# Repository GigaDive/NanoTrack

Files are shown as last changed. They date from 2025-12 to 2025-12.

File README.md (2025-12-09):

# NanoTrack v0.1: A Modular HCI Platform

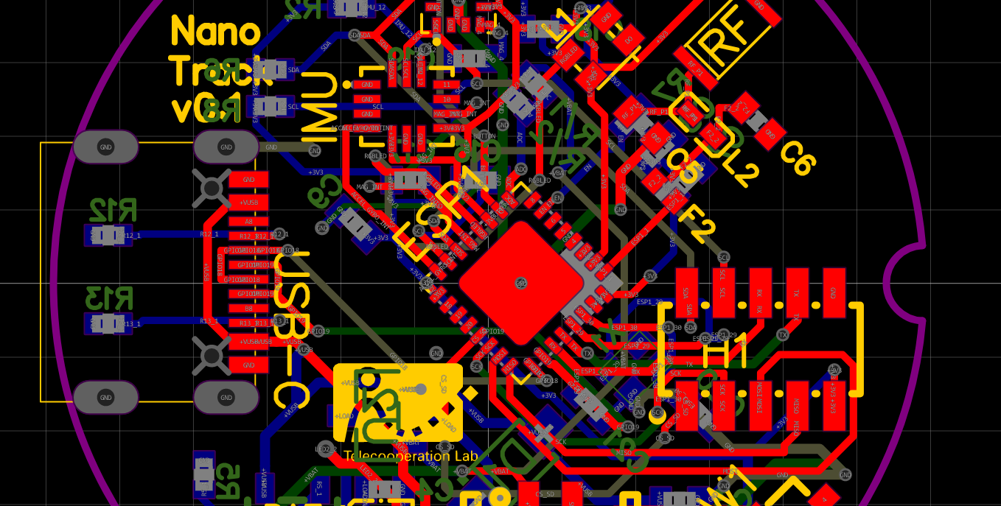
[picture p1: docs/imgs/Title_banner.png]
NanoTrack Board Wiring


The NanoTrack v0.1 is a versatile, small form-factor hardware platform for human-computer interaction (HCI) projects. Based on the ESP32-C3, it's designed for sensor data collection, actuator control, and direct device-to-device communication using ESP-NOW. Its modular design allows for easy expansion and customization.

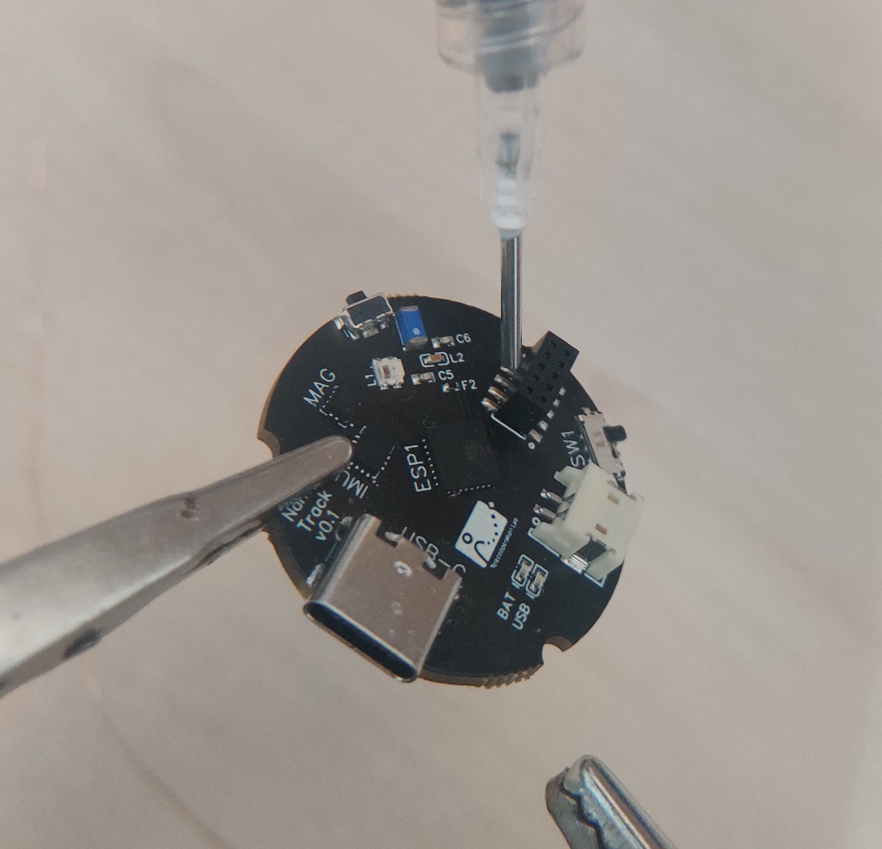
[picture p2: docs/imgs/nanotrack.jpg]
NanoTrack Board PCB


## Hardware

### Specifications

- **Processor**: ESP32-C3 (single-core RISC-V @ 160MHz)
- **Sensors**: Integrated 6-axis IMU (MPU-6050) with accelerometer and gyroscope.
- **Connectivity**: Wi-Fi, ESP-NOW, USB-C (for charging and programming).
- **Features**:
    - RGB-LED for status indication.
    - Physical LiPo battery disconnect switch.
    - User-programmable button.
    - Onboard battery charging and protection circuit.

### Pinout

| Function | PIN | Mode |
| --- | --- | --- |
| MISO | 24 | SPI |
| MOSI | 23 | SPI |
| SCK | 22 | SPI |
| CS_SD | 21 | SPI |
| SDA | 14 | I2C |
| SCL | 15 | I2C |
| Button | 10 | Input |
| RGB LED  | 12 | Output |
| Battery Voltage | 9 | Input |
| Accel /Gyro Programmable Interrupt 1  | 16 | Input |
| Accel /Gyro Programmable Interrupt 2 | 13 | Input |

### Modularity: Board-to-Board Connector

The NanoTrack is intended to use pogo pins for its modular board-to-board connections, allowing for a pressure-fit connection between the main board and extension modules. This design supports SPI, I2C, and serial communication for plug-and-play functionality. In its current state it uses dupon pin header as connection interface. A version with flatcables was also planned, but discarded.

### Casing

The project includes a 3D-printable case designed in Fusion 360. The current iteration is a round, pressure-fit case, with future designs moving towards using M2.5 brass standoffs for more robust mounting.

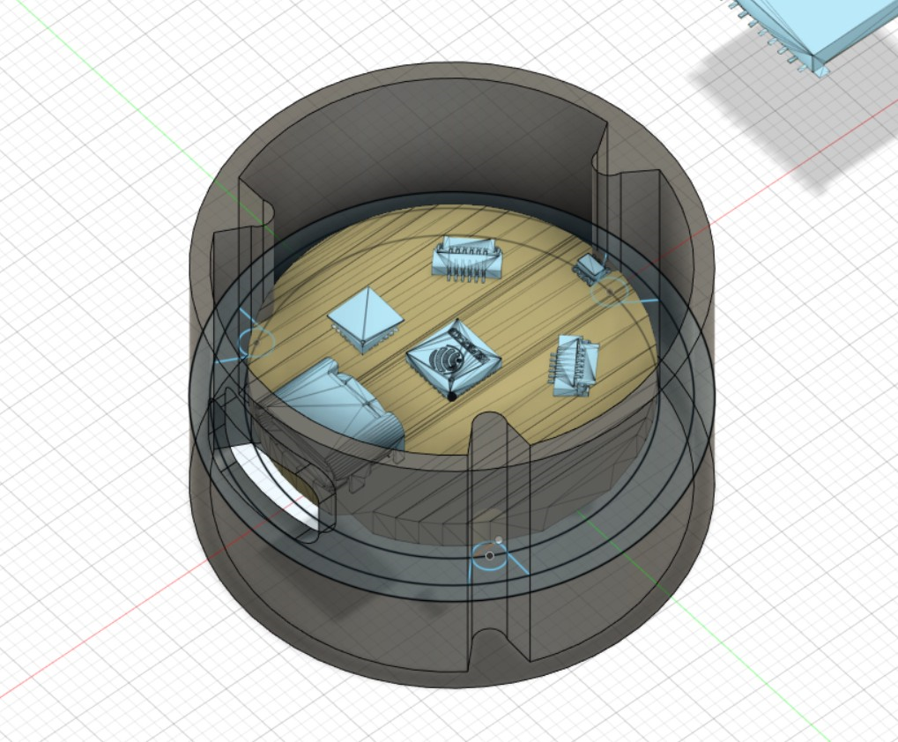
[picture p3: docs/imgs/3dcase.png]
3D Printed Case


### Schematics

- [Main Board Schematic (v0.4)](docs/v04/schematic_v04.pdf)
- [BME Module Schematic (v0.2)](docs/v02/schematic_module_v02.pdf)

Modules will always come in the exact same shape with three mounting dents and a data connector placed on the same location. Using I2C for example, we enable passthrough of the signals and later digitally assign them in code.  
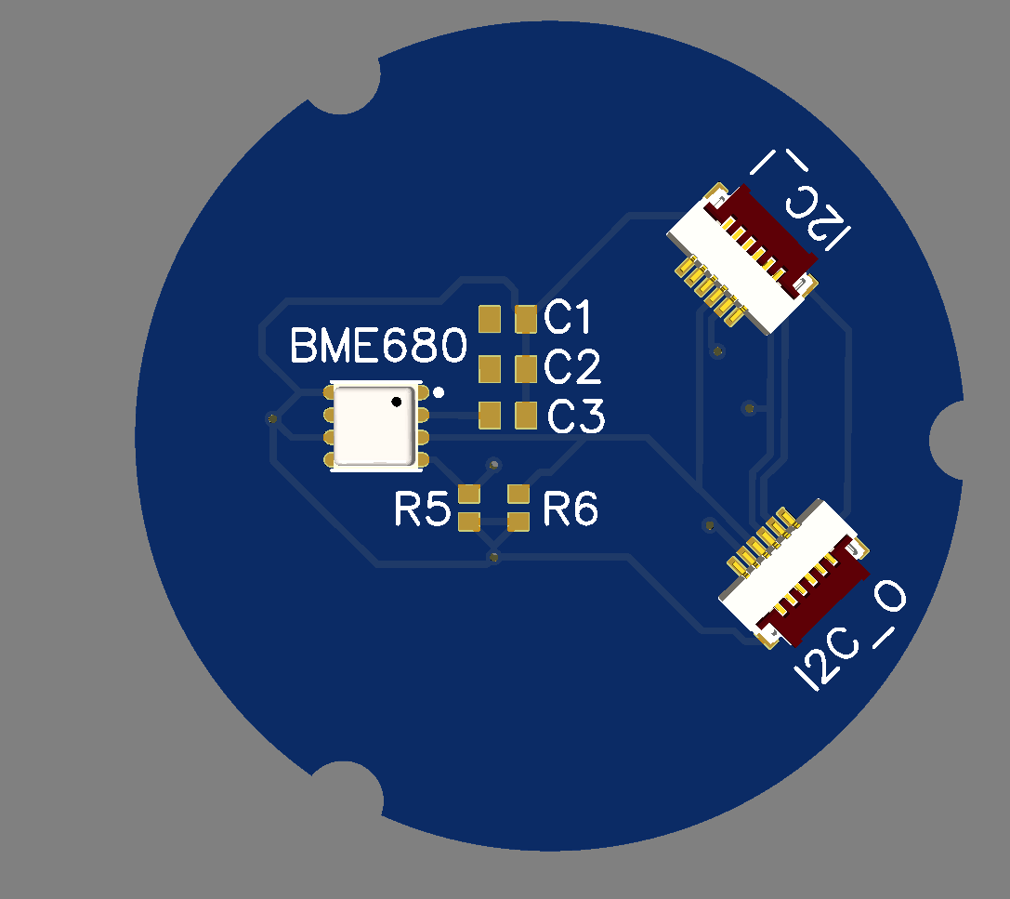
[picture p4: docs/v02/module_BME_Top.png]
BME Module


## Software

### ESP8266/ESP32 Firmware

The firmware is developed using PlatformIO and the Arduino framework. Its primary functions are:

1.  **IMU Data Acquisition**: It initializes the MPU-6050 and uses its Digital Motion Processor (DMP) to get fused sensor data (quaternions, yaw/pitch/roll, and acceleration).
2.  **Wi-Fi Communication**: The device connects to a Wi-Fi network and streams the IMU data over UDP to a specified host IP address.

To get started with the firmware:
1.  Open the `dev/ESP8266/IMU_testbed` directory in an IDE with PlatformIO.
2.  Create a `credentials.h` file in the `src` directory (you can copy `credentials_default.h`) and add your Wi-Fi credentials.
3.  Build and upload the firmware to the NanoTrack board.

### Python Host Application

The host application is a Python script that:

1.  **Receives IMU Data**: It runs a UDP server that listens for data from the NanoTrack.
2.  **Visualizes Orientation**: Using the `vtk` library, it visualizes the device's orientation in 3D space by rotating an object according to the quaternion data received from the IMU.

The main script for this is `dev/python/imu_backend.py`.

## Getting Started

1.  **Hardware Setup**: Connect a LiPo battery to the NanoTrack and turn on the power switch.
2.  **Firmware**: Flash the firmware from the `dev/ESP8266/IMU_testbed` directory to the device.
3.  **Host Application**: Run the `imu_backend.py` script on a computer connected to the same network as the NanoTrack. The script will start listening for UDP packets.
4.  **Visualization**: The Python script will open a window showing a 3D object that mirrors the orientation of the NanoTrack device in real-time.

**This project was ended in a very early stage in development. It is intended as a blueprint for future developments with microcontrollers, modular architectures and general-purpose computing in mind. 

## Development Journey

This section outlines the challenges, learnings, and future direction of the NanoTrack project, based on development notes.

### Issues During Development

- **Power Delivery**: The LDO (MIC5504) was found to be too weak (300mA) for powering multiple modules; a 1-2A regulator is needed.
- **Boot Mode**: The ESP32-C3 requires specific GPIO pins (GPIO8, GPIO9) to be pulled up or down to enter the correct boot or download mode. The initial design lacked dedicated boot/reset buttons.
- **LDO Enable Pin**: The enable (EN) pin of the LDO was not connected, preventing it from turning on.
- **Component Sizing**: The RGB LED required 5V, not 3.3V. I2C pull-up resistors needed to be adjusted to 4.7kΩ.

### Key Learnings

- **Component Selection is Critical**: The choice of LDO and other power components must be carefully matched to the current requirements of the entire system.
- **Read the Datasheet Carefully**: Issues like the LDO's enable pin and the ESP32's strapping pins for boot mode selection could have been avoided by closer inspection of the datasheets.
- **Hardware Debugging**: A systematic approach is necessary when debugging hardware, such as checking for continuity, verifying voltage levels at different points, and isolating components.
- **Simulation**: Proper simulation of all hardware components and modules, including the logic of the wiring schematic in the EDA software should be done before handing over to manufacturer. 

### Future Outlook

- **Hardware Revisions (v0.2)**:
    - Add polarity markings (+/-) for the battery connector.
    - Use a vertical-mount battery connector for a better fit.
    - Standardize on JST 1.25mm connectors instead of the less common JST-ZH 1.5mm.
    - Improve component spacing on the PCB for easier assembly.
    - Add boot and reset buttons.
    - Implement a more powerful, adjustable LDO.
- **Case Design**: Design and 3D print a new case that accommodates M2.5mm spacers for a more secure assembly.
- **Software Enhancements**: Explore more advanced sensor fusion algorithms and expand the capabilities of the Python visualization tool.

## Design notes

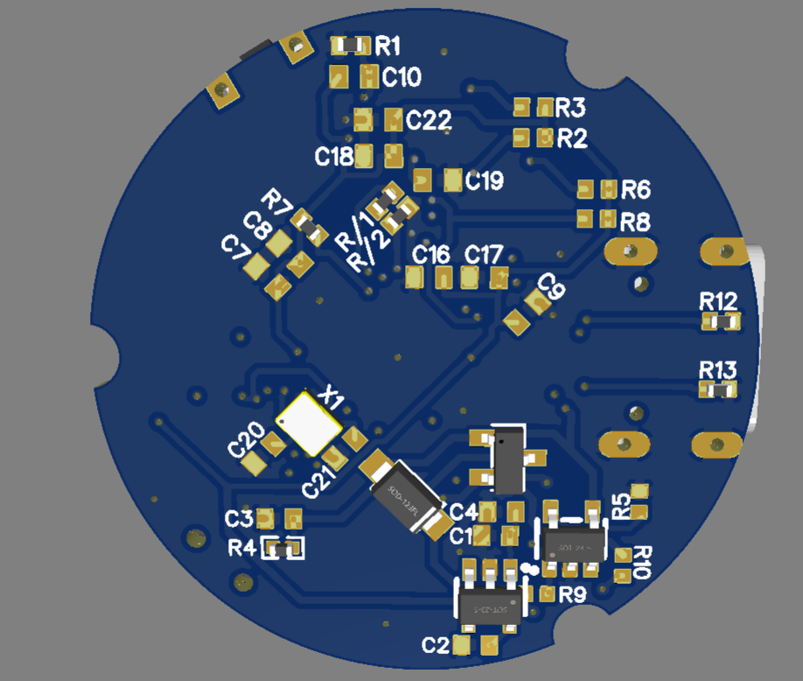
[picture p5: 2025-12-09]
docs/v05/back.png

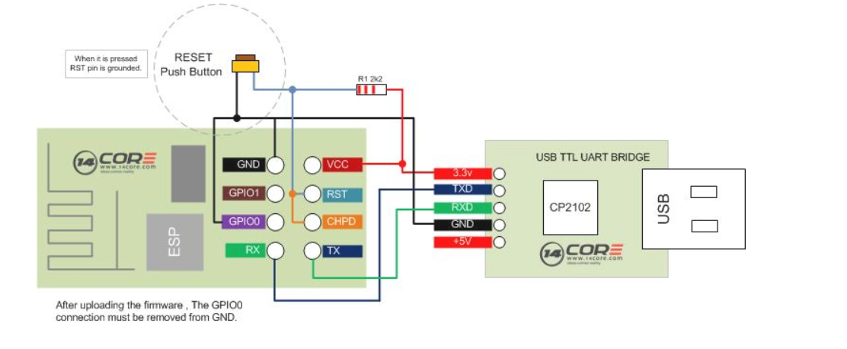
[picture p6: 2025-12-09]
docs/uart_flashing.png

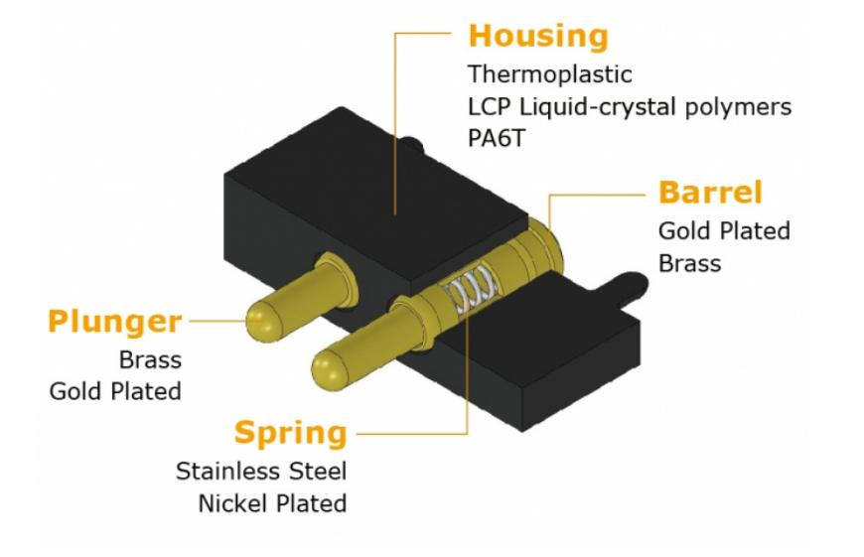
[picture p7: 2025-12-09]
docs/imgs/pogopins.png

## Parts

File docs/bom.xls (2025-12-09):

Comment | Designator | Footprint | JLCPCB Part #
10k | R2,R3,R6,R7,R8 | R0402 | C60490
S2B-ZR-SM4A-TF(LF)(SN) | CN2 | CONN-SMD_S2B-ZR-SM4A | C265329
250k | R/2 | R0402 | C159061
2.4pF | C5 | C0402 | C260623
FC-F1005HRK-620H5 | BAT,USB | LED0402-RD | C130719
5.1k | R12,R13 | R0402 | C325521
MIC5504-3.3YM5-TR | U3 | SOT-23-5_L3.0-W1.7-P0.95-LS2.8-TL | C88419
MK-11C04-G013 | SW1 | SW-SMD_MK-11C04-G013 | C778185
DMP1045UQ-7 | U2 | SOT-23-3_L2.9-W1.3-P1.83-LS2.4-BR-1 | C177033
ESP32_C3_QFN32 | ESP1 | QFN32 | C2838500
DSK24_C908229 | D1 | SOD-123FL_L2.7-W1.8-LS3.8-RD | C908229
0.1uF | C8,C9,C10,C16,C17,C18,C19 | C0402 | C106209
10u | C7 | C0402 | C163694
MCP73831T-2ATI/OT | U4 | SOT-23-5_L3.0-W1.7-P0.95-LS2.8-BR | C14879
1M | R/1 | R0402 | C138033
1.27mmFemaleheader2*5 | H1 | HDR-SMD_10P-P1.27-V-F-R2-C5-S1.27-LS4.8 | C59983
10k | R1 | R0402 | C375970
ANT3216LL00R2400A | RF | ANT3216LL00R2400A | C293767
2k | R9,R10,R5 | R0402 | C100449
SKTDLDE010 | SW2 | KEY-SMD_SKTDLDE010 | C115365
3.3pF | C6 | C0402 | C326841
WS2812_2020 | L1 | WS2812_2020 | C965555
2.2nH | L2 | L0402 | C77120
10p | C20,C21 | C0402 | C32949
LIS3MDLTR | MAG | LGA-12_L2.0-W2.0-P0.50-BL | C478483
USB_C_C393939 | USB-C | USBC_C393939 | C2858270
100k | R4 | R0402 | C176119
XTAL_2016 | X1 | XTYL_2016 | C383840
4u7 | C3 | C0402 | C527032
1u | C1,C2,C4,C22 | C0402 | C106253
0 | F2 | R0402 | C514781
LSM6DSRTR | IMU | LGA-14_L3.0-W2.5-P0.50-BR | C784817

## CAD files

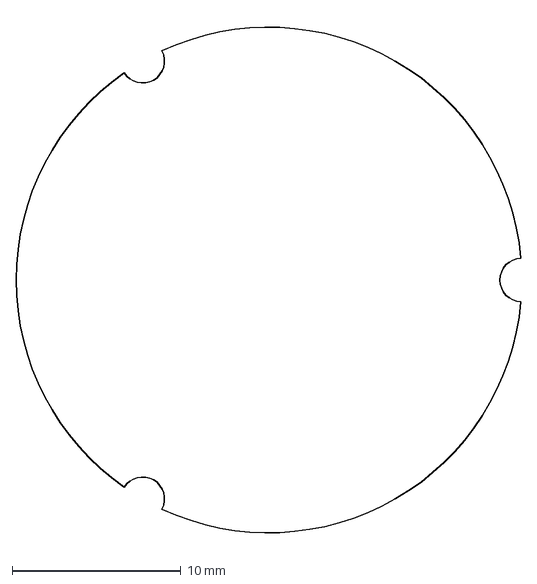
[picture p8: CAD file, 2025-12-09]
case/Board_outline.dxf
29.9 x 31.3 mm

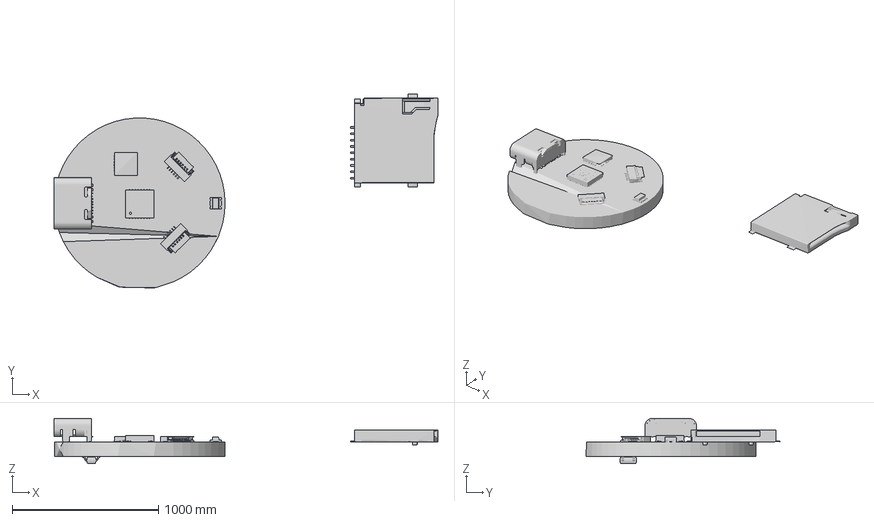
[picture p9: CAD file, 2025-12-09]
case/OBJ_PCB_motion capture testbed_4.3mf
2628.0 x 1327.1 x 309.0 mm

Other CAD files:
case/OBJ_PCB_motion capture testbed_4.obj

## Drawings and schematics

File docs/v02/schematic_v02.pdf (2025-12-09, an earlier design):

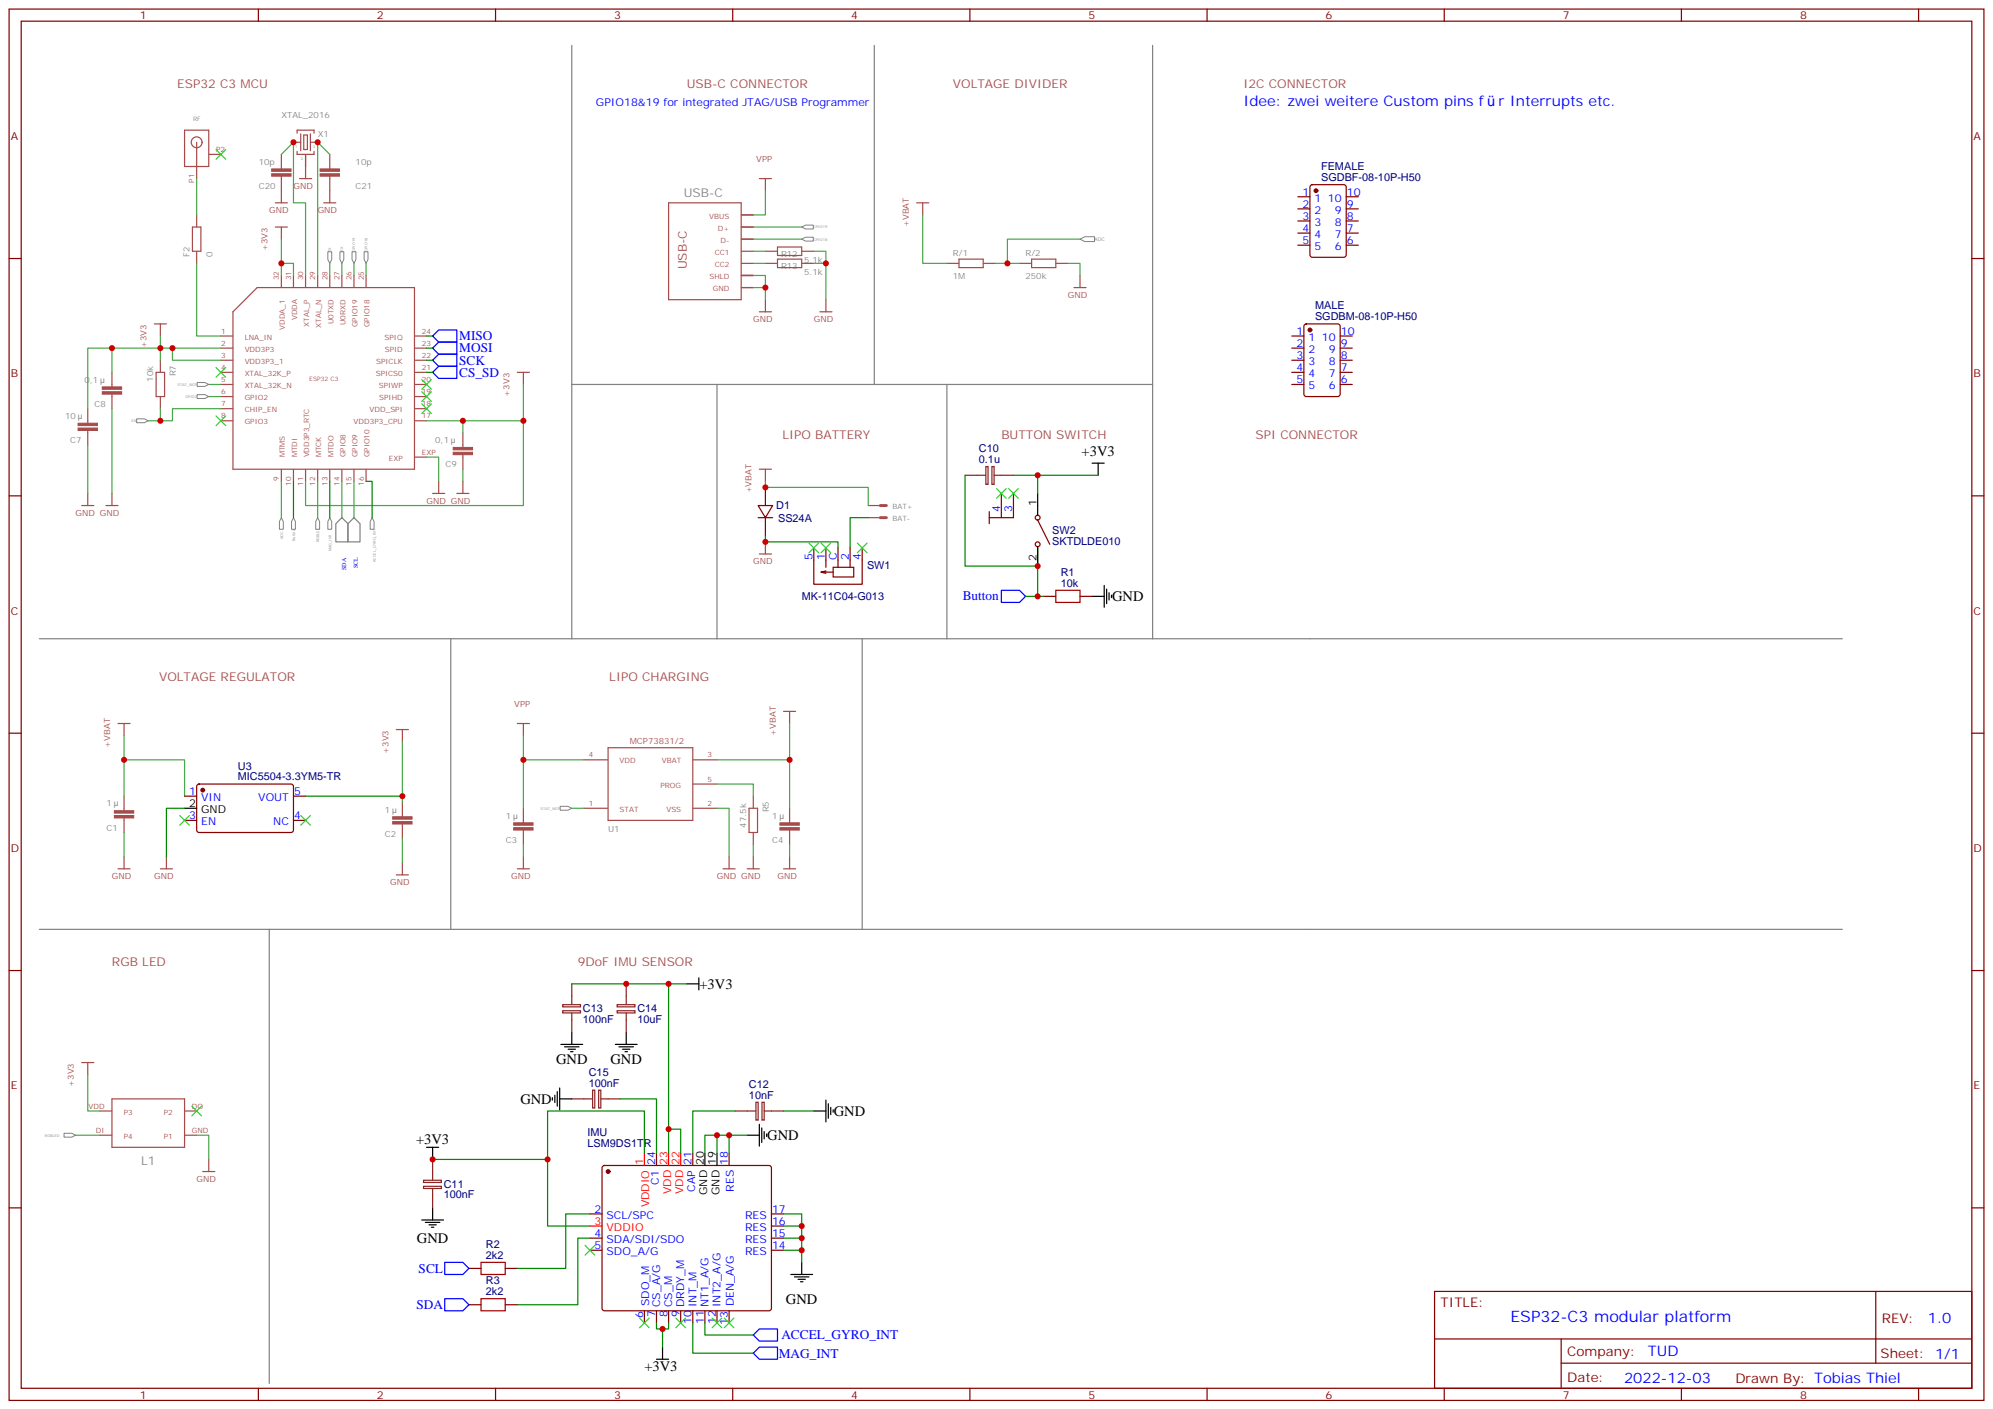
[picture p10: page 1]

I2C CONNECTOR
Idee: zwei weitere Custom pins f r Interrupts etc.

GPIO18&19 for integrated JTAG/USB Programmer

RES 14 RES 15 RES 16 RES 17

Drawn By: Tobias Thiel

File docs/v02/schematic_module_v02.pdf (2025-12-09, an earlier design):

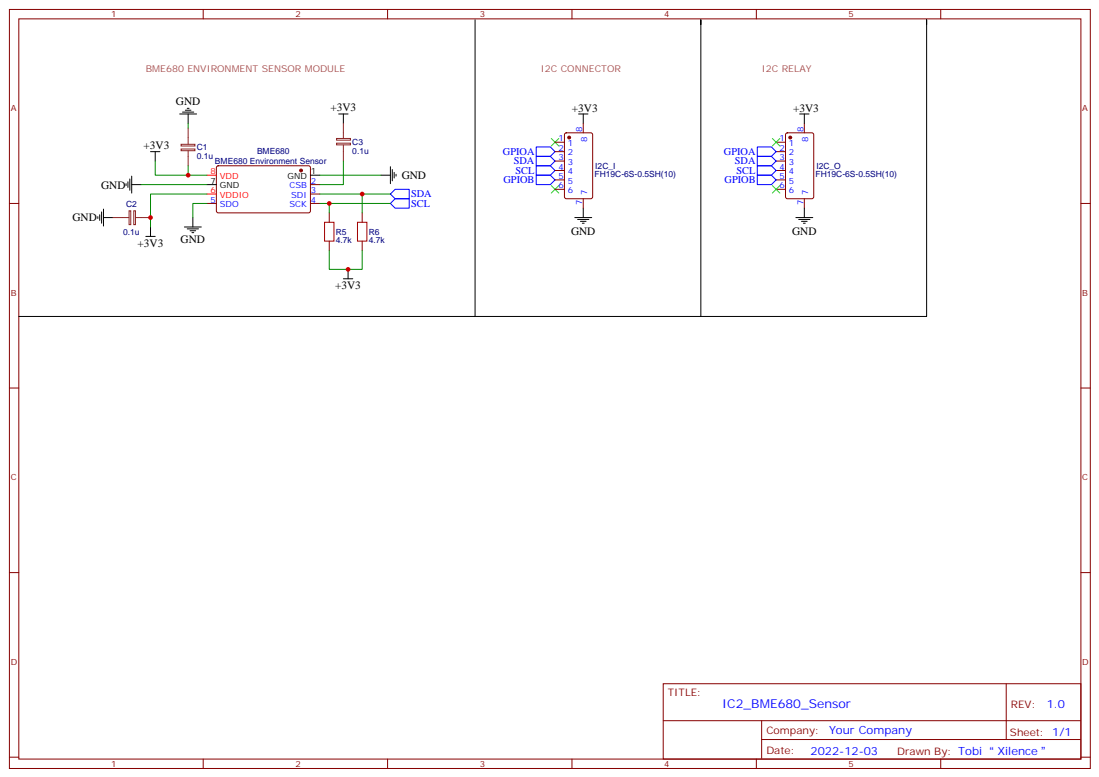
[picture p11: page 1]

Drawn By: Tobi Xilence

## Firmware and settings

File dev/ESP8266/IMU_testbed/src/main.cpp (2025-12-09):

#include <Arduino.h>
#include <ESP8266WiFi.h> // Include the Wi-Fi library
#include <WiFiUdp.h>
#include "credentials.h"
#include <Wire.h>
#include "global_types.h"
#include "mpu6050_simple.h"
#include "mpu6050_dmp.h"

unsigned int UDP_PORT = 1330;
unsigned int UDP_REMOTE = 4210;
WiFiUDP UDP;
IMU6050_full IMU6050_Measurement;
IMU6050_DMP IMU6050_dmp;
unsigned long timer = millis();
int32_t loopCounter = 0;
char packet[255];
char reply[400];
// IPAddress remoteIP(192,168,0,121);
const char *remoteIP = "192.168.0.121";
void setup()
{
  Serial.begin(115200); // Start the Serial communication to send messages to the computer
  delay(10);
  Serial.println('\n');

  WiFi.begin(ssid, password); // Connect to the network
  Serial.print("Connecting to ");
  Serial.print(ssid);
  Serial.println(" ...");

  int i = 0;
  while (WiFi.status() != WL_CONNECTED)
  { // Wait for the Wi-Fi to connect
    delay(1000);
    Serial.print(++i);
    Serial.print(' ');
  }

  Serial.println('\n');
  Serial.println("Connection established!");
  Serial.print("IP address:\t");
  Serial.println(WiFi.localIP()); // Send the IP address of the ESP8266 to the computer

  UDP.begin(UDP_PORT);
  Serial.print("Listening on UDP port ");
  Serial.println(UDP_PORT);
  // init_mpu6050();
  mpu6050_dmp_setup();
  IMU6050_dmp.sequence_number = 0;
}

void loop()
{
  if (millis() > timer + 1000)
  {
    Serial.print("Loop/s:   ");
    Serial.println(loopCounter);
    loopCounter = 0;
    timer = millis();
  }
  // loop_mpu6050(&IMU6050_Measurement);
  mpu6050_dmp_loop(&IMU6050_dmp);
  IMU6050_dmp.wifi_rssi = WiFi.RSSI();
  // sprintf(reply, "%f,%f,%f,%f,%f,%f,%f",
  // IMU6050_Measurement.accel.acceleration.x,
  // IMU6050_Measurement.accel.acceleration.y,
  // IMU6050_Measurement.accel.acceleration.z,
  // IMU6050_Measurement.gyro.gyro.x,
  // IMU6050_Measurement.gyro.gyro.y,
  // IMU6050_Measurement.gyro.gyro.z,
  // IMU6050_Measurement.temp.temperature
  // );
  // sprintf(reply, "Quaternions: %f,%f,%f,%f\nYPR:%f,%f,%f\nACCEL_WORLD:%d,%d,%d\nACCEL_REAL:%d,%d,%d\nTEMP: %f RSSI: %d SQN:%ld\n",
  sprintf(reply, "%f,%f,%f,%f,%f,%f,%f,%d,%d,%d,%d,%d,%d,%f,%d,%ld\n",
          IMU6050_dmp.q.w,
          IMU6050_dmp.q.x,
          IMU6050_dmp.q.y,
          IMU6050_dmp.q.z,
          IMU6050_dmp.ypr[0],
          IMU6050_dmp.ypr[1],
          IMU6050_dmp.ypr[2],
          IMU6050_dmp.accel_with_gravity.x,
          IMU6050_dmp.accel_with_gravity.y,
          IMU6050_dmp.accel_with_gravity.z,
          IMU6050_dmp.accel_without_gravity.x,
          IMU6050_dmp.accel_without_gravity.y,
          IMU6050_dmp.accel_without_gravity.z,
          IMU6050_dmp.temp,
          IMU6050_dmp.wifi_rssi,
          IMU6050_dmp.sequence_number);
  UDP.beginPacket(remoteIP, UDP_REMOTE);
  UDP.write(reply, sizeof(reply));
  UDP.endPacket();
  IMU6050_dmp.sequence_number = IMU6050_dmp.sequence_number + 1;
  loopCounter++;

}

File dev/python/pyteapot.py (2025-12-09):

"""
PyTeapot module for drawing rotating cube using OpenGL as per
quaternion or yaw, pitch, roll angles received over serial port.
"""

import pygame
import math
import socket
from OpenGL.GL import *
from OpenGL.GLU import *
from pygame.locals import *


class DMP_Object:
    def __init__(self,qw,qx,qy,qz,ypr,accel_with_gravity,accel_without_gravity,temp,rssi,seq):
        self.qw = qw
        self.qx = qx
        self.qy = qy
        self.qz = qz
        self.ypr = ypr
        self.accel_with_gravity = accel_with_gravity
        self.accel_without_gravity = accel_without_gravity
        self.temp = temp
        self.rssi = rssi
        self.seq = seq

useSerial = False # set true for using serial for data transmission, false for wifi
useQuat = False   # set true for using quaternions, false for using y,p,r angles
dmpdata={"qw":0.0,"qx":0.0,"qy":0.0,"qz":0.0,"raw":None}
current_state = DMP_Object(0,0,0,0,[0,0,0],[0,0,0],[0,0,0],0,0,0)

if(useSerial):
    import serial
    ser = serial.Serial('/dev/ttyUSB0', 38400)
else:
    UDP_IP = "0.0.0.0"
    UDP_PORT = 4210
    sock = socket.socket(socket.AF_INET, # Internet
                         socket.SOCK_DGRAM) # UDP
    sock.bind((UDP_IP, UDP_PORT))
    sock.sendto(bytes("Hello device", "utf-8"), ("192.168.0.64", 1330))


def main():
    video_flags = OPENGL | DOUBLEBUF
    pygame.init()
    screen = pygame.display.set_mode((960, 720), video_flags)
    pygame.display.set_caption("PyTeapot IMU orientation visualization")
    resizewin(960, 720)
    init()
    frames = 1
    ticks = pygame.time.get_ticks()
    fps = 0
    while 1:
        event = pygame.event.poll()
        if event.type == QUIT or (event.type == KEYDOWN and event.key == K_ESCAPE):
            break
        if(useQuat):
            [w, nx, ny, nz, temp, rssi] = read_data()
        else:
            [yaw, pitch, roll, temp, rssi] = read_data()
        if(useQuat):
            draw(w, nx, ny, nz,fps,temp, rssi)
        else:
            draw(1, yaw, pitch, roll, fps ,temp, rssi)
        pygame.display.flip()
        frames += 1
        fps = ((frames*1000)/(pygame.time.get_ticks()-ticks))
    print("fps: %d" % ((frames*1000)/(pygame.time.get_ticks()-ticks)))
    if(useSerial):
        ser.close()


def resizewin(width, height):
    """
    For resizing window
    """
    if height == 0:
        height = 1
    glViewport(0, 0, width, height)
    glMatrixMode(GL_PROJECTION)
    glLoadIdentity()
    gluPerspective(45, 1.0*width/height, 0.1, 100.0)
    glMatrixMode(GL_MODELVIEW)
    glLoadIdentity()


def init():
    glShadeModel(GL_SMOOTH)
    glClearColor(0.0, 0.0, 0.0, 0.0)
    glClearDepth(1.0)
    glEnable(GL_DEPTH_TEST)
    glDepthFunc(GL_LEQUAL)
    glHint(GL_PERSPECTIVE_CORRECTION_HINT, GL_NICEST)


def cleanSerialBegin():
    if(useQuat):
        try:
            line = ser.readline().decode('UTF-8').replace('\n', '')
            w = float(line.split('w')[1])
            nx = float(line.split('a')[1])
            ny = float(line.split('b')[1])
            nz = float(line.split('c')[1])
        except Exception:
            pass
    else:
        try:
            line = ser.readline().decode('UTF-8').replace('\n', '')
            yaw = float(line.split('y')[1])
            pitch = float(line.split('p')[1])
            roll = float(line.split('r')[1])
        except Exception:
            pass


def read_data():
    if(useSerial):
        ser.reset_input_buffer()
        cleanSerialBegin()
        line = ser.readline().decode('UTF-8').replace('\n', '')
        print(line)
    else:
        # Waiting for data from udp port 5005
        data, address = sock.recvfrom(4096)
        data = data.decode("utf-8").replace('\x00','').strip("\n").split(",")
        data[15] = data[15]
        current_state = DMP_Object(
        float(data[0]),float(data[1]),float(data[2]),float(data[3]),#Quaternion
        [float(data[4]),float(data[5]),float(data[6])],#YPR 
        [int(data[7]),int(data[8]),int(data[9])],#Accel with gravity
        [int(data[10]),int(data[11]),int(data[12])],#Accel without gravity
        float(data[13]),float(data[14]),data[15])
        dmpdata["raw"] = current_state
        dmpdata["qw"] = current_state.qw
        dmpdata["qx"] = current_state.qx
        dmpdata["qy"] = current_state.qy
        dmpdata["qz"] = current_state.qz
        return [current_state.ypr[0],current_state.ypr[1],current_state.ypr[2] ,current_state.temp, current_state.rssi]
        #return [current_state.qw,current_state.qx,current_state.qy,current_state.qz]
                
    # if(useQuat):
    #     w = float(line.split('w')[1])
    #     nx = float(line.split('a')[1])
    #     ny = float(line.split('b')[1])
    #     nz = float(line.split('c')[1])
    #     return [w, nx, ny, nz, current_state.temp, current_state.rssi]
    # else:
    #     yaw = float(line.split('y')[1])
    #     pitch = float(line.split('p')[1])
    #     roll = float(line.split('r')[1])
    #     return [yaw, pitch, roll, current_state.temp, current_state.rssi]
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
